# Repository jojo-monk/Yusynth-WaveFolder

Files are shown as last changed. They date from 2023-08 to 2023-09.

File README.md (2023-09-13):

# Yusynth-WaveFolder
Adaptation du Yusynth [WaveFolder](http://yusynth.net/Modular/index_en.html) au format Eurorack
Testé et fonctionnel

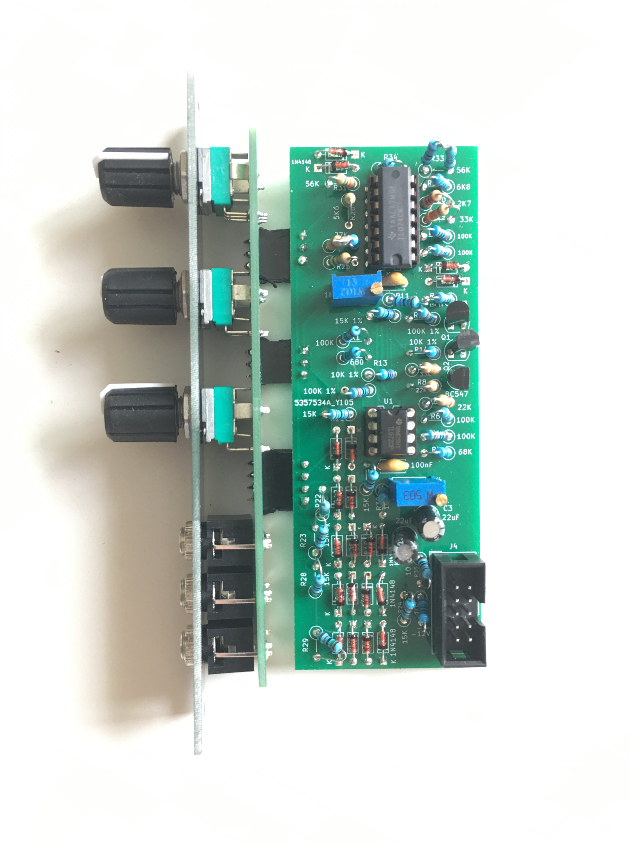
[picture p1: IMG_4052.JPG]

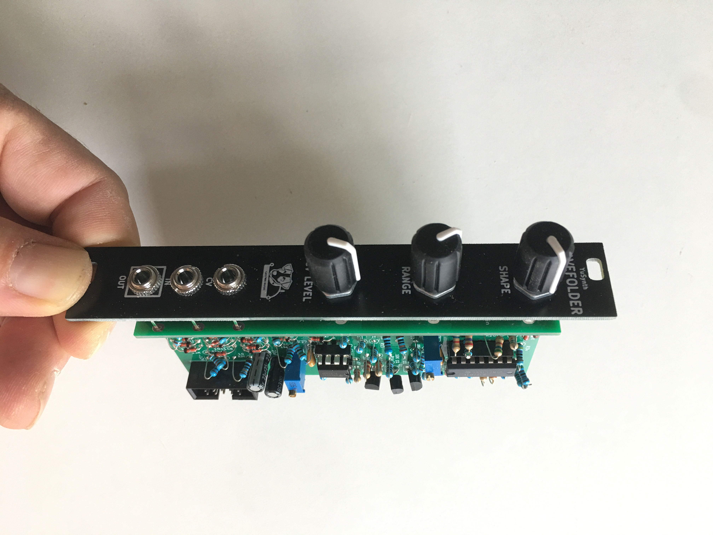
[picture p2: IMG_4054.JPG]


[Build document](https://htmlpreview.github.io/?https://github.com/jojo-monk/Yusynth-WaveFolder/blob/main/ibom.html)

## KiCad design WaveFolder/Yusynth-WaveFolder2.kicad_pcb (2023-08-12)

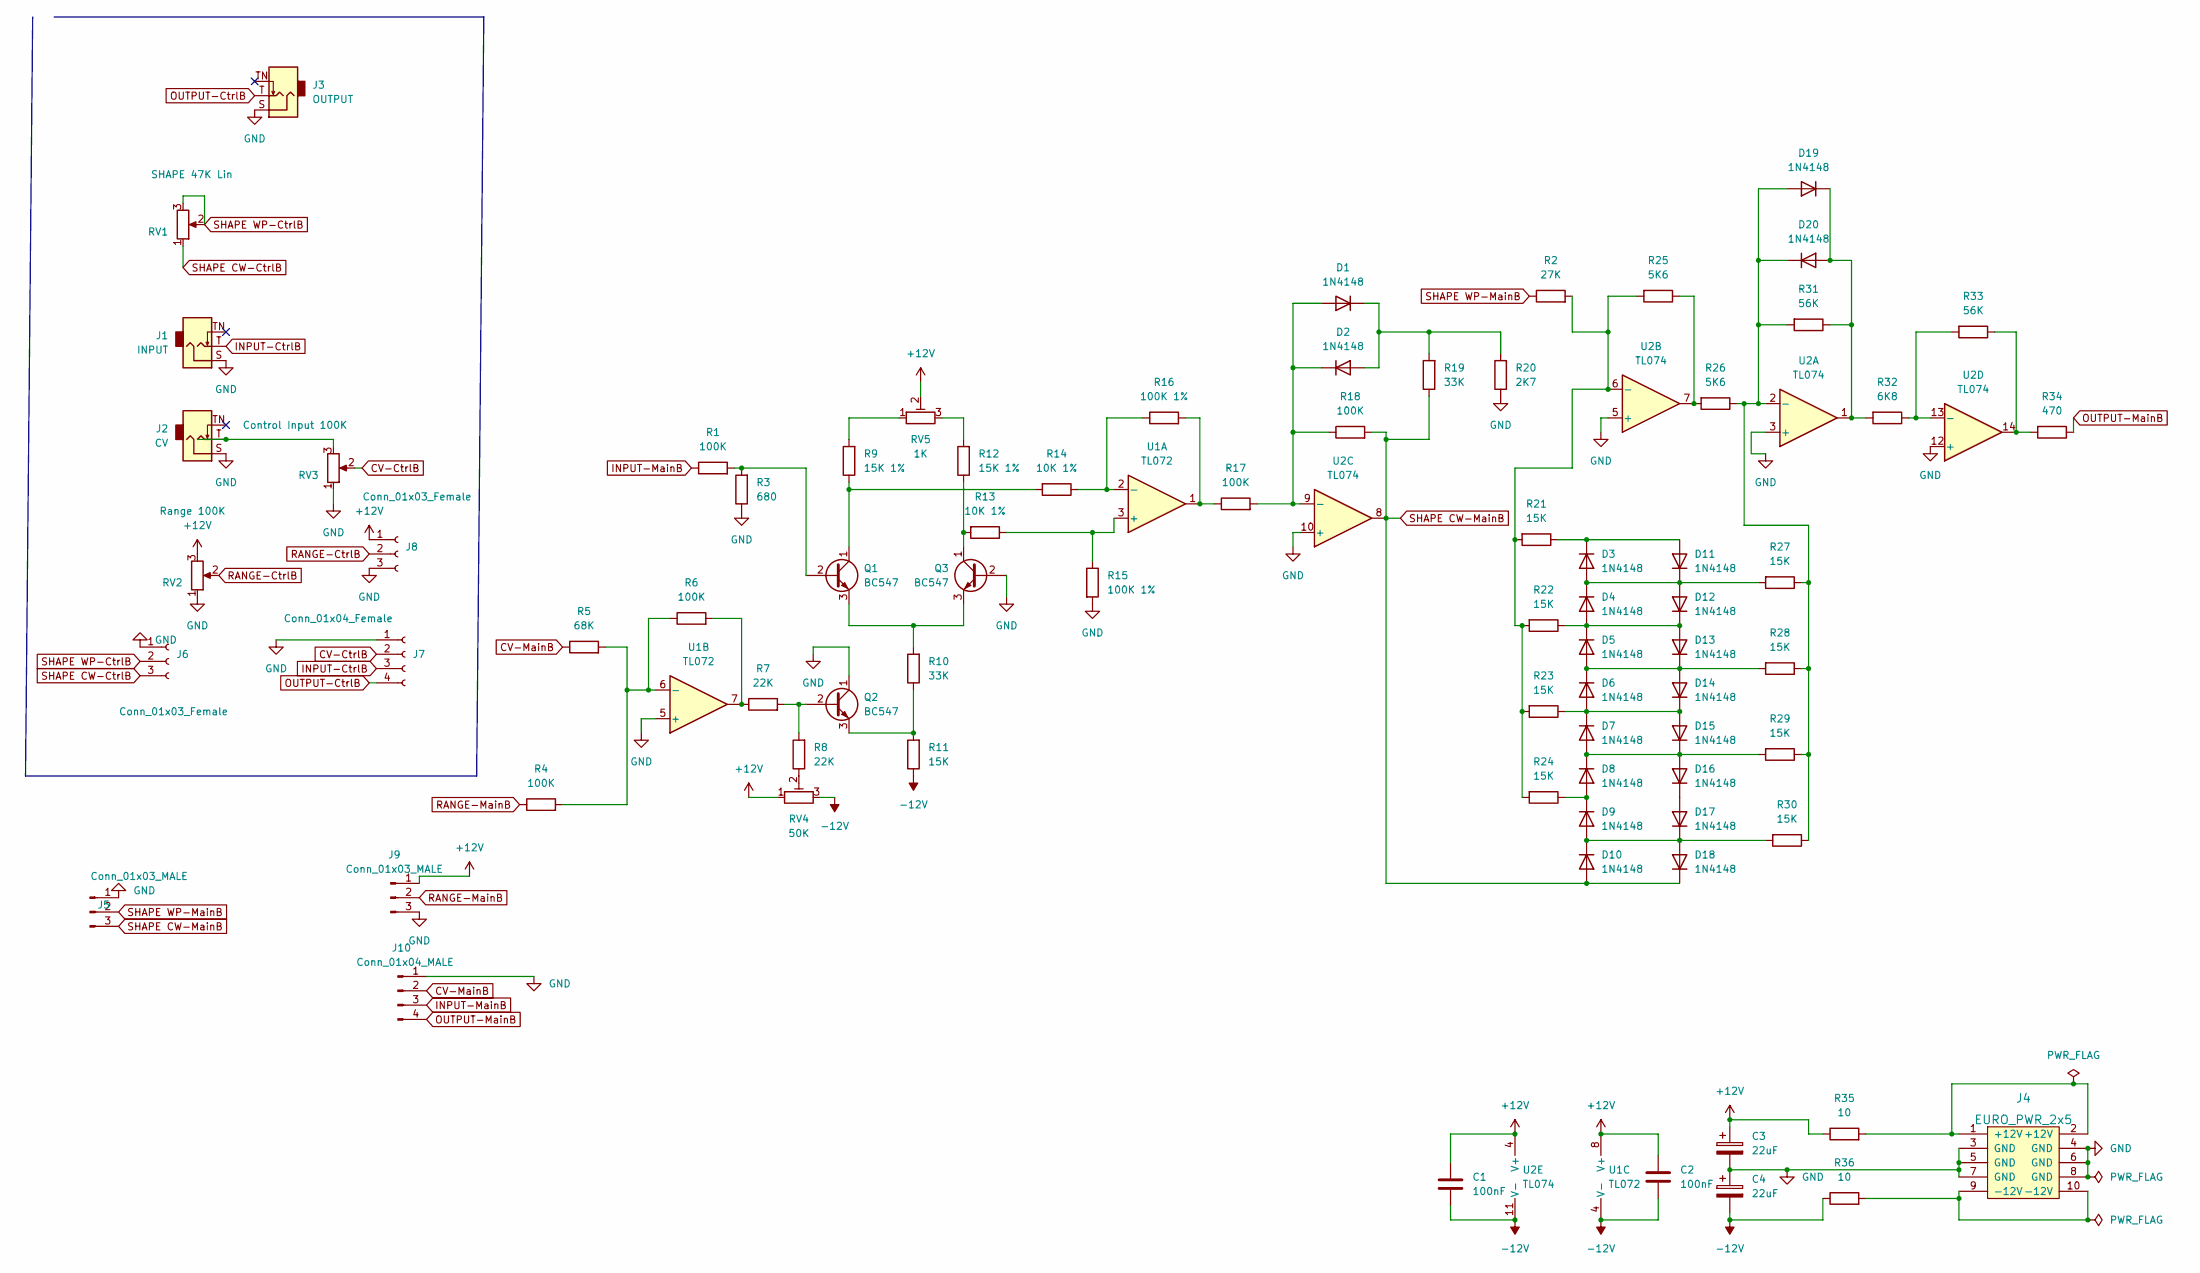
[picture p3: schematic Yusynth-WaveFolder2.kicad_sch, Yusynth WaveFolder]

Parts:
C1, C2: 100nF; C_Disc_D5.0mm_W2.5mm_P5.00mm
C3, C4: 22uF; CP_Radial_D5.0mm_P2.00mm
D1, D2, D3, D4, D5, D6, D7, D8, D9, D10, D11, D12, D13, D14, D15, D16, D17, D18, D19, D20: 1N4148; D_DO-35_SOD27_P7.62mm_Horizontal
J1: INPUT; Jack_3.5mm_QingPu_WQP-PJ398SM_Vertical
J2: CV; Jack_3.5mm_QingPu_WQP-PJ398SM_Vertical
J3: OUTPUT; Jack_3.5mm_QingPu_WQP-PJ398SM_Vertical
J4: EURO_PWR_2x5; Eurorack_power_header
J5, J9: Conn_01x03_MALE; PinHeader_1x03_P2.54mm_Vertical
J6, J8: Conn_01x03_Female; PinHeader_1x03_P2.54mm_Vertical
J7: Conn_01x04_Female; PinHeader_1x04_P2.54mm_Vertical
J10: Conn_01x04_MALE; PinHeader_1x04_P2.54mm_Vertical
Q1, Q2, Q3: BC547; TO-92_HandSolder
R1, R4, R6, R17, R18: 100K; R_Axial_DIN0207_L6.3mm_D2.5mm_P5.08mm_Vertical
R2: 27K; R_Axial_DIN0207_L6.3mm_D2.5mm_P5.08mm_Vertical
R3: 680; R_Axial_DIN0207_L6.3mm_D2.5mm_P5.08mm_Vertical
R5: 68K; R_Axial_DIN0207_L6.3mm_D2.5mm_P5.08mm_Vertical
R7, R8: 22K; R_Axial_DIN0207_L6.3mm_D2.5mm_P5.08mm_Vertical
R9, R12: 15K 1%; R_Axial_DIN0207_L6.3mm_D2.5mm_P5.08mm_Vertical
R10, R19: 33K; R_Axial_DIN0207_L6.3mm_D2.5mm_P5.08mm_Vertical
R11, R21, R22, R23, R24, R27, R28, R29, R30: 15K; R_Axial_DIN0207_L6.3mm_D2.5mm_P5.08mm_Vertical
R13, R14: 10K 1%; R_Axial_DIN0207_L6.3mm_D2.5mm_P5.08mm_Vertical
R15, R16: 100K 1%; R_Axial_DIN0207_L6.3mm_D2.5mm_P5.08mm_Vertical
R20: 2K7; R_Axial_DIN0207_L6.3mm_D2.5mm_P5.08mm_Vertical
R25, R26: 5K6; R_Axial_DIN0207_L6.3mm_D2.5mm_P5.08mm_Vertical
R31, R33: 56K; R_Axial_DIN0207_L6.3mm_D2.5mm_P5.08mm_Vertical
R32: 6K8; R_Axial_DIN0207_L6.3mm_D2.5mm_P5.08mm_Vertical
R34: 470; R_Axial_DIN0207_L6.3mm_D2.5mm_P5.08mm_Vertical
R35, R36: 10; R_Axial_DIN0207_L6.3mm_D2.5mm_P5.08mm_Vertical
RV1: SHAPE 47K Lin; Potentiometer_Alpha_RD901F-40-00D_Single_Vertical
RV2: Range 100K; Potentiometer_Alpha_RD901F-40-00D_Single_Vertical
RV3: Control Input 100K; Potentiometer_Alpha_RD901F-40-00D_Single_Vertical
RV4: 50K; Potentiometer_Bourns_3266Y_Vertical
RV5: 1K; Potentiometer_Bourns_3266Y_Vertical
U1: TL072; DIP-8_W7.62mm_LongPads
U2: TL074; DIP-14_W7.62mm_LongPads

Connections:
+12V: C1.1, C2.1, C3.1, J8.1, J9.1, R35.1, RV2.3, RV4.1, RV5.2, U1.8 (V+), U2.4 (V+)
-12V: C1.2, C2.2, C4.2, R11.1, R36.1, RV4.3, U1.4 (V-), U2.11 (V-)
CV-CtrlB: J7.2, RV3.2
CV-MainB: J10.2, R5.1
GND: C3.2, C4.1, J1.S, J2.S, J3.S, J4.3 (GND), J4.4 (GND), J4.5 (GND), J4.6 (GND), J4.7 (GND), J4.8 (GND), J5.1, J6.1, J7.1, J8.3, J9.3, J10.1, Q2.1 (C), Q3.2 (B), R3.1, R15.2, R20.1, RV2.1, RV3.1, U1.5 (+), U2.3 (+), U2.5 (+), U2.10 (+), U2.12 (+)
INPUT-CtrlB: J1.T, J7.3
INPUT-MainB: J10.3, R1.1
unnamed: D1.1 (K), D2.2 (A), R19.2, R20.2
unnamed: D1.2 (A), D2.1 (K), R17.2, R18.1, U2.9 (-)
unnamed: D8.2 (A), D9.1 (K), R24.1
unnamed: D9.2 (A), D10.1 (K), D17.1 (K), D18.2 (A), R30.2
unnamed: D3.2 (A), D4.1 (K), D11.1 (K), D12.2 (A), R27.2
unnamed: D3.1 (K), D11.2 (A), R21.1
unnamed: D4.2 (A), D5.1 (K), D12.1 (K), D13.2 (A), R22.1
unnamed: D5.2 (A), D6.1 (K), D13.1 (K), D14.2 (A), R28.2
unnamed: D6.2 (A), D7.1 (K), D14.1 (K), D15.2 (A), R23.1
unnamed: D7.2 (A), D8.1 (K), D15.1 (K), D16.2 (A), R29.2
unnamed: D16.1 (K), D17.2 (A)
unnamed: D19.1 (K), D20.2 (A), R31.1, R32.2, U2.1
unnamed: D19.2 (A), D20.1 (K), R26.1, R27.1, R28.1, R29.1, R30.1, R31.2, U2.2 (-)
unnamed: J2.T, RV3.3
unnamed: J4.1 (+12V), J4.2 (+12V), R35.2
unnamed: J4.9 (-12V), J4.10 (-12V), R36.2
unnamed: Q1.1 (C), R9.1, R14.2
unnamed: Q1.2 (B), R1.2, R3.2
unnamed: Q1.3 (E), Q3.3 (E), R10.2
unnamed: Q2.2 (B), R7.2, R8.2
unnamed: Q2.3 (E), R10.1, R11.2
unnamed: Q3.1 (C), R12.1, R13.2
unnamed: R2.2, R21.2, R22.2, R23.2, R24.2, R25.2, U2.6 (-)
unnamed: R4.2, R5.2, R6.1, U1.6 (-)
unnamed: R6.2, R7.1, U1.7
unnamed: R8.1, RV4.2
unnamed: R9.2, RV5.1
unnamed: R12.2, RV5.3
unnamed: R13.1, R15.1, U1.3 (+)
unnamed: R14.1, R16.1, U1.2 (-)
unnamed: R16.2, R17.1, U1.1
unnamed: R25.1, R26.2, U2.7
unnamed: R32.1, R33.2, U2.13 (-)
unnamed: R33.1, R34.2, U2.14
OUTPUT-CtrlB: J3.T, J7.4
OUTPUT-MainB: J10.4, R34.1
RANGE-CtrlB: J8.2, RV2.2
RANGE-MainB: J9.2, R4.1
SHAPE CW-CtrlB: J6.3, RV1.1
SHAPE CW-MainB: D10.2 (A), D18.1 (K), J5.3, R18.2, R19.1, U2.8
SHAPE WP-CtrlB: J6.2, RV1.2, RV1.3
SHAPE WP-MainB: J5.2, R2.1

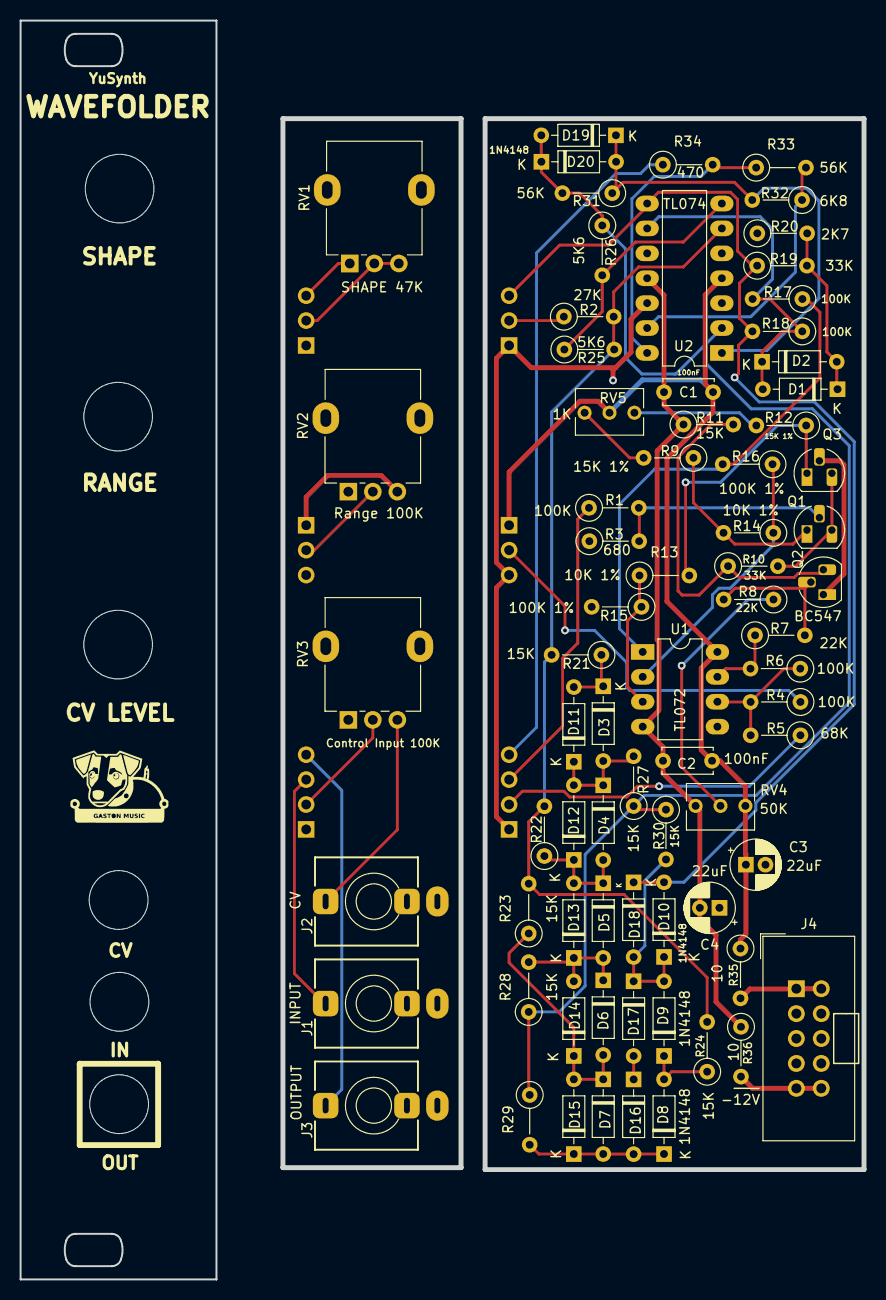
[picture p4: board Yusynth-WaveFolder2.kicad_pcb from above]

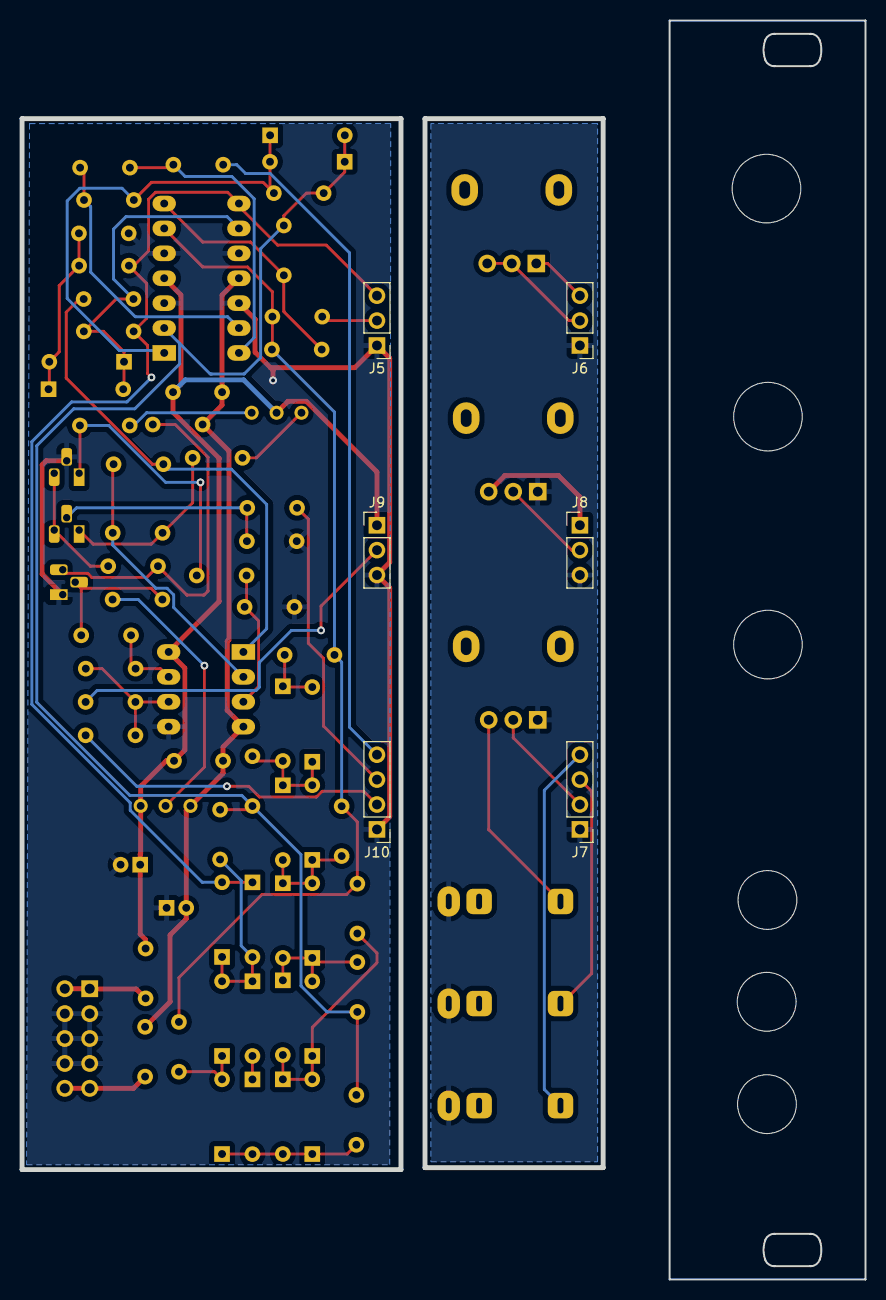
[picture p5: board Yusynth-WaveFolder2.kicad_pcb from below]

Board: 2 copper layers, 86.0 x 128.4 mm, 80 parts (6 on the bottom side), 49 nets.
